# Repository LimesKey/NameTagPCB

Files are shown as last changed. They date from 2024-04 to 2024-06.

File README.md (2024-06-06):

[Apocalypse's](https://apocalypse.hackclub.com/) official name tag badge PCB for every participant to wear during the event. Designed in KiCad with help from other hack clubbers, it has a handful of LEDs powered by dual LIR2032 batteries. For sourcing power to the batteries, the board has a wireless charging and NFC Capabilities as well a USB-C port for flashing and charging.

## Full-Design PCB

|Apocalypse PCB Front|Apocalypse PCB Back|
|:-:|:-:|
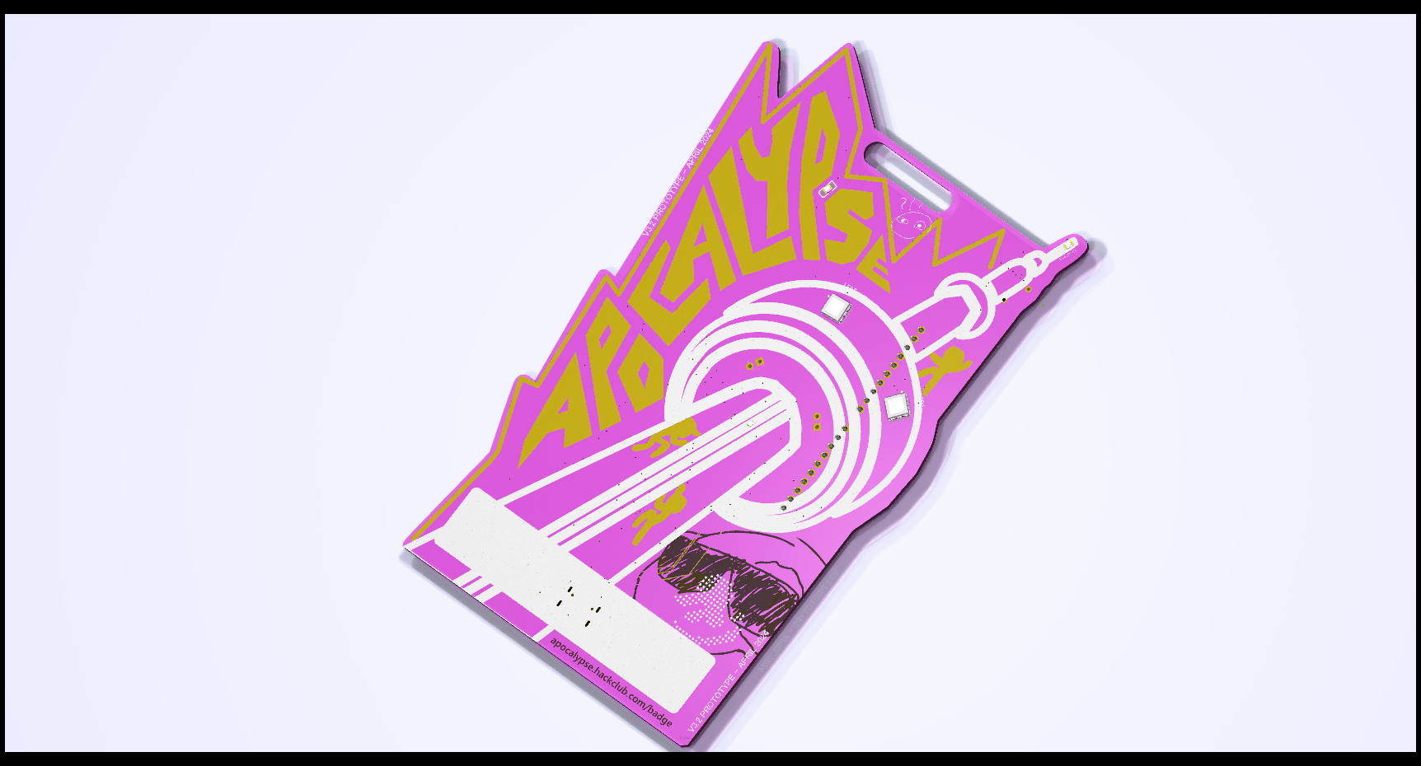
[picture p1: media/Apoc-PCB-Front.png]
Apocalypse PCB Front
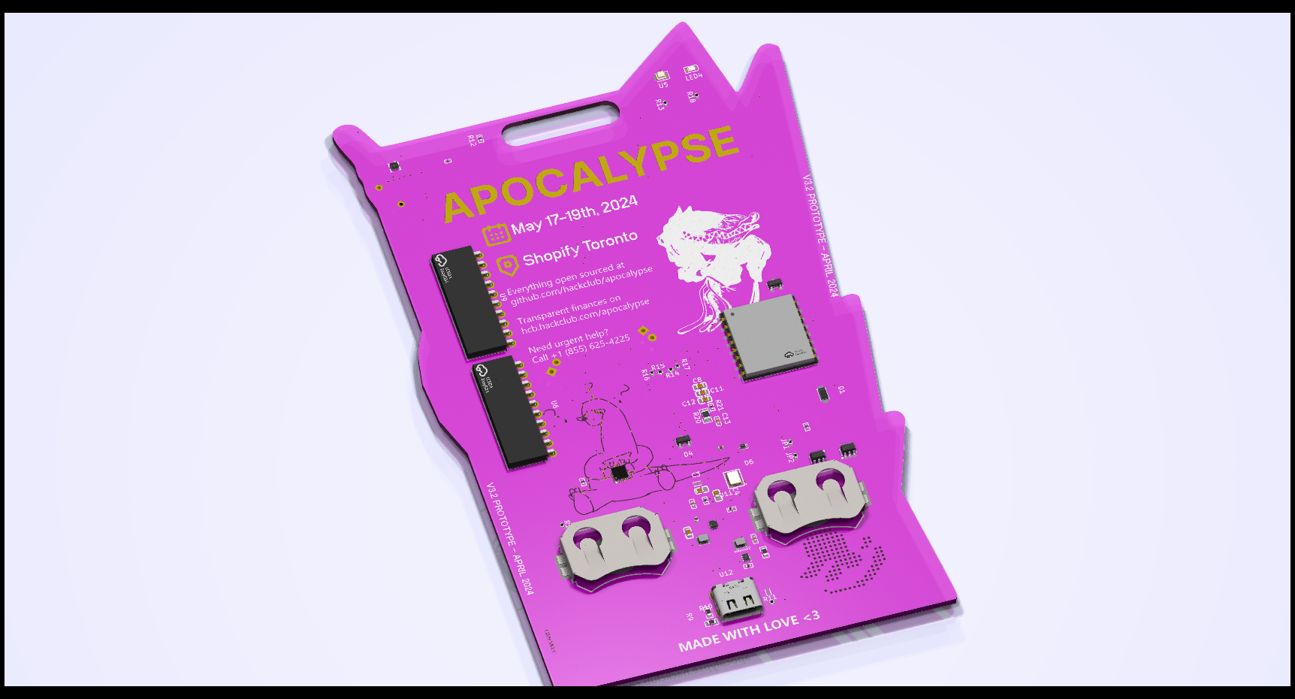
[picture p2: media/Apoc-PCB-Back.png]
Apocalypse PCB Back
| "Apocalypse PCB Front")|  "Apocalypse PCB Back"

## Simple-Design PCB

|Apocalypse PCB Front|Apocalypse PCB Back|
|:-:|:-:|
|Apocalypse PCB Front "Apocalypse PCB Front")| Apocalypse PCB Back "Apocalypse PCB Back"

## [PCBWay](https://www.pcbway.com/)
PCBWay has been enormously helpful with getting my design manufactured and brought to life, with their supportive engineers highlighting possible complications with my design, and their rapid and low-cost manufacturing, it's been a pleasure working with them. PCBWay allowed us to supply all 150 high-school hackers with a nametag badge PCB each. Soldering classes were run and people had a blast seeing my design choices and learning how the PCB worked and was put together.

PCBWay Logo

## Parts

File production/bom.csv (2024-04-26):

Designator | Footprint | Quantity | Value | LCSC Part #
BT1, BT3 | BAT-SMD_MY-2032-12 | 2 | MY-2032-12 | C964833
C1 | 0402 | 1 | 220nF | C7503518
C11, C12, C8 | C0603 | 3 | 10uF | C1691
C13 | C0402 | 1 | 120pF | C5186895
C2 | C0603 | 1 | 4.7uF | C380325
C3, C4 | C0603 | 2 | CL10A226MQ8NRNE | C159801
C5, C6 | 0402 | 2 | 20pF | C376774
C7 | C0402 | 1 | 470pF | C424858
D4, D5, D6 | SOD-523_L1.2-W0.8-LS1.6-RD | 3 | RB521S30T1G | C145179
D7, D8 | SOD-123_L2.8-W1.8-LS3.7-RD | 2 | SS14 | C2909920
L3 | 0603 | 1 | SCL1608LR47KSP 470nH | C411944
L4 | 0603 | 1 | SCL1608LR47KSP | C411944
LED1, LED5 | LED-SMD_6P-L5.0-W5.0-TL | 2 | WS2813B-V5 | C965558
LED2 | LED0805-RD_GREEN | 1 | XL-2835UPC-02 | C965815
LED3 | LED0805-RD_GREEN | 1 | Detect NFC | C965815
LED4 | LED0603-RD_GREEN | 1 | BatteryIndicator Green | C965805
Q1, Q2 | SOT-23-3_L2.9-W1.3-P1.90-LS2.4-BR | 2 | S8050 | C2846756
Q3 | SOT-23-6_L2.9-W1.6-P0.95-LS2.8-BR | 1 | FS8205A | C908265
R1 | 0402 | 1 | R47 | C327820
R10 | R0402 | 1 | 10 | C25139
R11, R15 | R0402 | 2 | 75 | C103159
R12, R2 | 0402 | 2 | 5.1k | C103086
R13 | 0402 | 1 | R470 | C25167
R14 | R0402 | 1 | 150 | C25143
R16 | R0805 | 1 | 45.3k | C218586
R18 | 0402 | 1 | R510 | C2909366
R21 | 0402 | 1 | R10k | C2906885
R3 | R0402 | 1 | 100k | C3017514
R4 | R0402 | 1 | 100Ω | C2906884
R5 | R0402 | 1 | R1.5k | C2929900
R6 | R0805 | 1 | 56k | C104415
R7 | R0402 | 1 | 1kΩ | C2906899
R9 | R0402 | 1 | 10k | C327797
U1 | XQFN-8_L1.6-W1.6-P0.50-BL | 1 | NT3H2111W0FHKH | C710403
U11, U12 | C0201 | 2 | 100nF | C5142565
U2 | SOT-563_L1.6-W1.2-P0.50-LS1.6-BR | 1 | TPS61023DRLR | C919459
U3 | SOT-23-6 | 1 | DW01A_C351410 | C18164398
U4 | VSON-6_L1.5-W1.5-P0.50-TL | 1 | TLV62595DMQR | C3189969
U5 | 0805 | 1 | BatteryIndicator Red | C5879378
U6, U9 | HDR-TH_10P-P2.54-H-F-W10.0-N | 2 | PM254-1-10-W-8.5 | C2897392
U7 | QFN-20_L3.0-W3.0-P0.40-TL-EP1.7 | 1 | CH32V003F4U6 | C5299908
U8 | LED0603-RD | 1 | NCD0603B5 | C7429915
USB1 | TYPE-C-TH_MC-313D | 1 | MC-313D | C428461
X1 | CRYSTAL-SMD_4P-L3.2-W2.5-BL | 1 | S3224000081040D1JB | C700764

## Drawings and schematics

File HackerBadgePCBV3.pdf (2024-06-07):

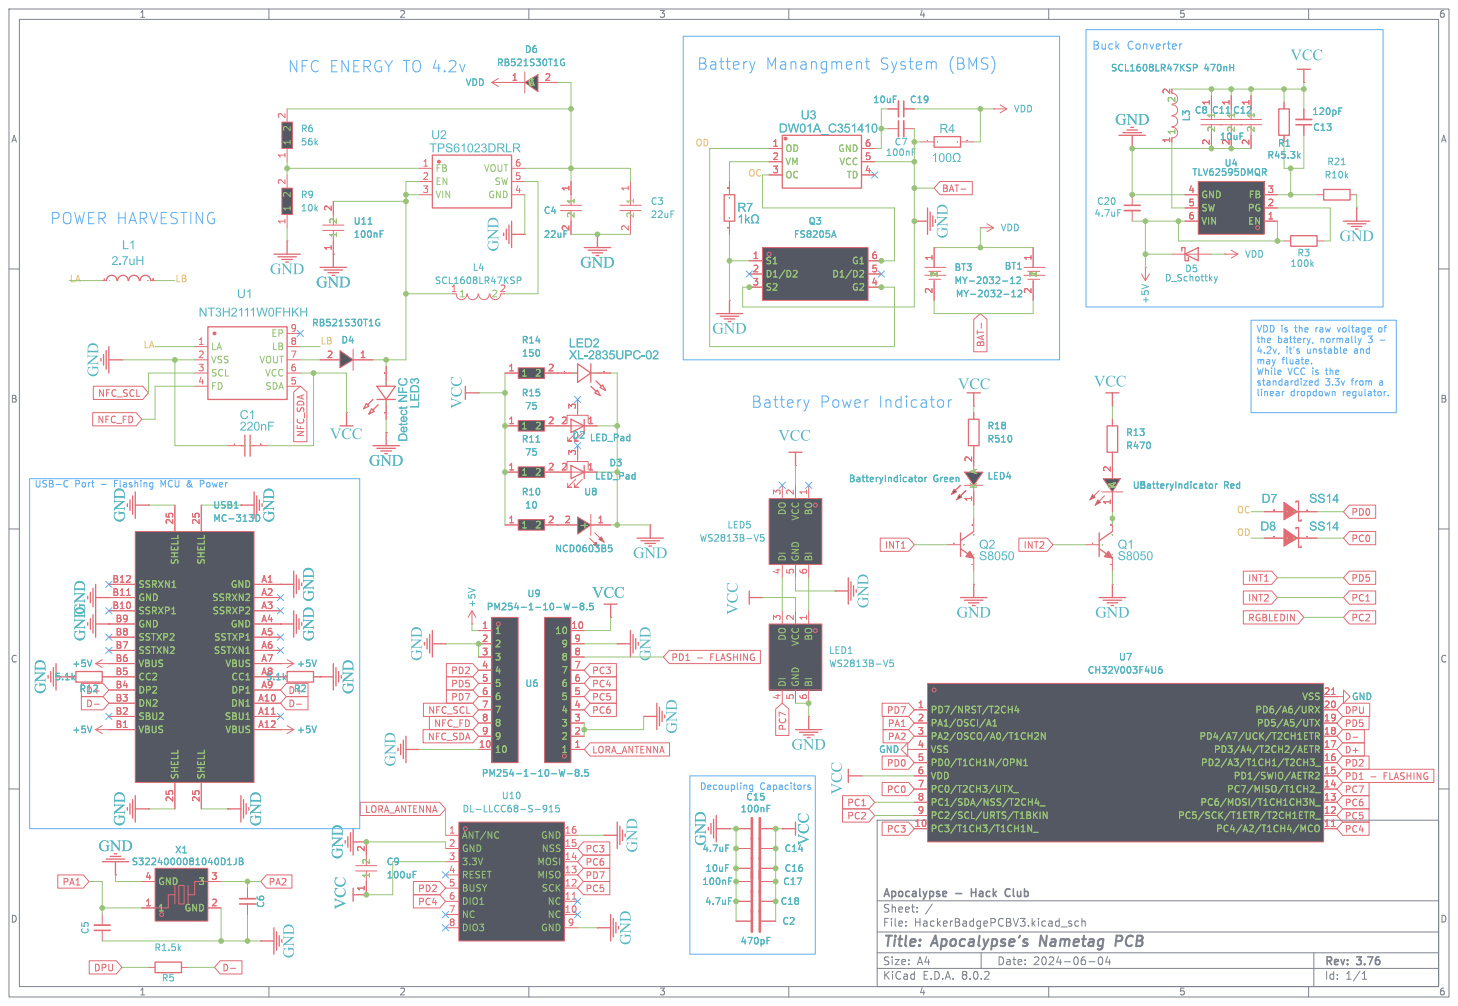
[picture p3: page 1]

2 U7 CH32V003F4U6 PD7/NRST/T2CH4 1 PC3/T1CH3/T1CH1N_ 10 PC4/A2/T1CH4/MCO 11 PC5/SCK/T1ETR/T2CH1ETR_ 12 PC6/MOSI/T1CH1CH3N_ 13 PC7/MISO/T1CH2_ 14 PD1/SWIO/AETR2 15 PD2/A3/T1CH1/T2CH3_ 16 PD3/A4/T2CH2/AETR 17 PD4/A7/UCK/T2CH1ETR 18 PD5/A5/UTX 19 PA1/OSCI/A1 2 PD6/A6/URX 20 VSS 21 PA2/OSCO/A0/T1CH2N 3 VSS 4 PD0/T1CH1N/OPN1 5 VDD 6 PC0/T2CH3/UTX_ 7 PC1/SDA/NSS/T2CH4_ 8 PC2/SCL/URTS/T1BKIN 9 BatteryIndicator Green LED4 K

Id: 1/1 Title: Apocalypse's Nametag PCB

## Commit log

2024-04-03 new changes to charge battery with 4.2v
    [HackerBadgePCBV3.kicad_sch]
2024-04-03 Add capacitor and resistor to NFC antenna
    [HackerBadgePCBV3.kicad_pcb, HackerBadgePCBV3.kicad_sch]
2024-04-04 add 3d viewer images from kicad
2024-04-06 update inductor
    [HackerBadgePCBV3.kicad_sch]
